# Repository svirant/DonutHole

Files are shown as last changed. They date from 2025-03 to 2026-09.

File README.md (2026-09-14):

# Donut Hole

**mini version of the [Donut Dongle](https://github.com/svirant/DonutDongle) that enables auto profiles for RS-232 based switches for the RetroTink 4K Pro/CE**
 - 3DP case now available on [MakerWorld](https://makerworld.com/en/models/1433467-donut-hole-for-retrotink-4k?from=search#profileId-1490991)
 - Compatible with the SVS
 - Connect multiple Donut Holes, Donut Dongles, gSerial Enablers simultaneously via a headphone jack splitter.
   - Must reflash "firmware" with offset variable set so SVS profile numbers don't overlap.
   - Up to 5 have been connected together simultaneously. More may be supported, but this is the max number I've been able to test.
 - Full instructions listed below for building your own!

> [!TIP]
> If DIY is not your thing. I have assembled versions available in my [Ko-fi](https://ko-fi.com/donutswdad/shop) shop.
</br>

> [!NOTE]
> *NEW* version allows:
> <br /> 
>   - **MT-VIKI Disconnection Detection** - when an input is powered off and on, the profile is resent.
>     - **Disable MT-VIKI beeping by pressing the "#" button on its remote.**
>   - **front case buttons/remote NOW change profiles on the MT-VIKI HDMI switch.** Thanks to [Arthrimus](https://scalablevideoswitch.com/)! 
>   - **auto-switching on Extron Matrix switchers** that support DSVP. Works with RGBS/HV and HDMI/DVI signal types.
>   - **Support for older Extron Crosspoint (non plus) matrix switchers**
>
> 
> <br /> For Matrix auto-switching, use the follow Options to enable:
> ```
> #define automatrixSW1 true // set true for auto matrix switching on "SW1" port
> #define automatrixSW2 false // set true for auto matrix switching on "SW2" port
>
> uint8_t ExtronVideoOutputPortSW1 = 1; // For older (E-series,non Plus/Ultra) Extron Matrix models, must specify the video output port that connects to RT4K
> uint8_t ExtronVideoOutputPortSW2 = 1; 
>
> uint8_t const vinMatrix[] = {0,  // MATRIX switchers  // When auto matrix mode is enabled: (automatrixSW1 / SW2 defined above)
>                                                        // set to 0 for the auto switched input to tie to all outputs
>                                                        // set to 1 for the auto switched input to trigger a Preset
>                                                        // set to 2 for the auto switched input to tie to "ExtronVideoOutputPortSW1" / "ExtronVideoOutputPortSW2"
>                                                        //
>                                                        // For option 1, set the following inputs to the desired Preset #
>                                                        // (by default each input # is set to the same corresponding Preset #)
> ```
<br />
<br />

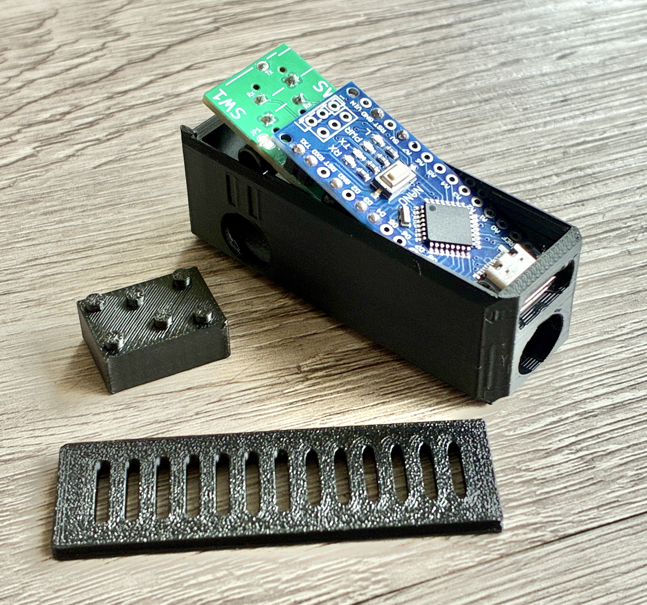
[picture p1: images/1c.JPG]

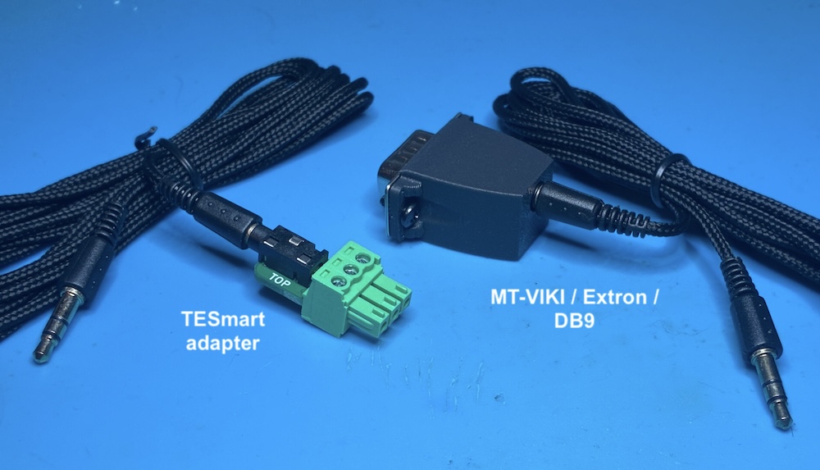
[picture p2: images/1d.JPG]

<br />

# Supported Switches
(current list, but not limited to)
| **Switch** | Supported | Notes |
| --- | --- |--- |
| TESmart 16x1 HDMI  | yes, confirmed first hand  | [Amazon](https://a.co/d/9XwZDlt) link for reference|
| TESmart 8x1 HDMI  | unconfirmed, but should work, let me know! | |
| MT-VIKI 8 port HDMI | yes, confirmed first hand | [Amazon](https://a.co/d/eHo5uKs) link for reference. **Disable MT-VIKI beeping by pressing the "#" button on it's remote.** |
| Extron RGBHV sw6  | yes, confirmed first hand  | auto-profiles triggered by manual selection or auto-switching |
| Extron SW4 VGA Ars | yes, confirmed by "Nobody" on the RT4K Discord | auto-profiles triggered by manual selection or auto-switching |
| Extron DXP 88 | yes, confirmed first hand | Auto-switching can be enabled in "Options" section of .ino.  Works with Presets. On SW1, Preset 1 is S1_ profile. On SW2, Preset 1 is S101_ profile, etc. <br><br>Power up the switch before connecting the DonutHole. |
| Extron CrossPoint Plus, MVX, etc | yes, confirmed by other users | Auto-switching can be enabled for switches that supports DSVP and are RGBS/HDMI/DVI signal types. By default, works with Presets as shown in the Note above. |
| Extron CrossPoint E-series  | yes, works with Presets and Input changes | Must set ExtronVideoOutputPortSW1 / SW2 variable to output connected to RT4K |

<br />

# Ordering PCBs
PCBs for this project:
 - [Donut Hole](https://github.com/svirant/DonutHole/blob/main/Donut_Hole.zip)
 - [VGA Adapter](https://github.com/svirant/DonutDongle/tree/main/Adapters) (VGAPassthrough or YC2VGA)
- (Optional) [TESmart_connector](https://github.com/svirant/DonutDongle/tree/main/Accessories)
- (Optional) [MT-VIKI / Extron / DB9 adapter](https://github.com/svirant/DonutDongle/tree/main/Accessories)
 
There are plenty of options for PCB manufacturing but I prefer [JLCPCB](https://jlcpcb.com) (No affiliation). Using the gerber (.zip) files provided, it's easy to place an order. Below are some tips/guidelines:
- 1.6mm Thickness
- For Surface Finish, "HASL(with lead)" is fine
- 4 Layer PCBs are the same cost as 2 Layer for the VGA Adapters. Because of that, the inner 2 layers are being used as ground planes for better EMI protection. Thanks to https://x.com/zaxour for the idea!
- "Remove Mark" option is now free on JLCPCB. Use it!
- All remaining default options should be fine
- Let me know if you have any questions!

# Assembly

[Interactive HTML BOM](https://svirant.github.io/DonutHole/images/ibom.html)

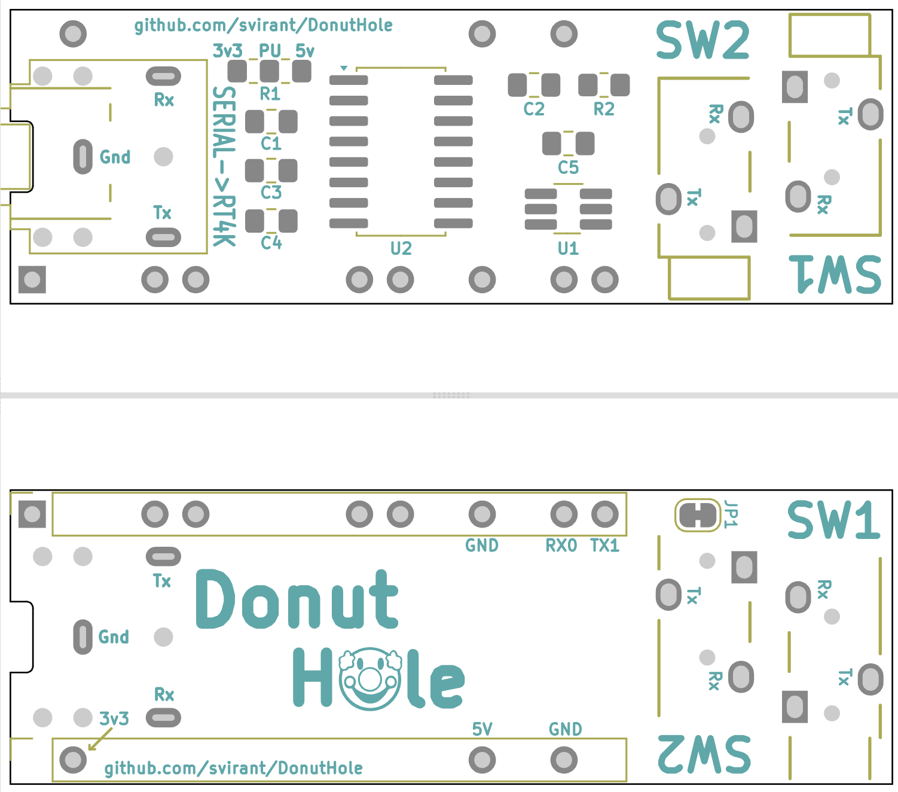
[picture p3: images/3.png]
[](https://svirant.github.io/DonutHole/images/ibom.html)

# (2M) baud mod
- **NOT supported with SVS connected to VGA adapter**
  - ...unless SDA/SDL trace is cut on VGA Adapter, but that disables the SVS's profile sending.
  - SVS runs at 9600 baud which conflicts with 2M regardless.
  - Extra Tx/Rx wire length of VGA cable can also cause issues. Workaround - You can cut SDA/SDL traces on the bottom of the VGA adapter to continue passing video but disables "VGA cable Serial" passthrough. (How the SVS sends profile changes)

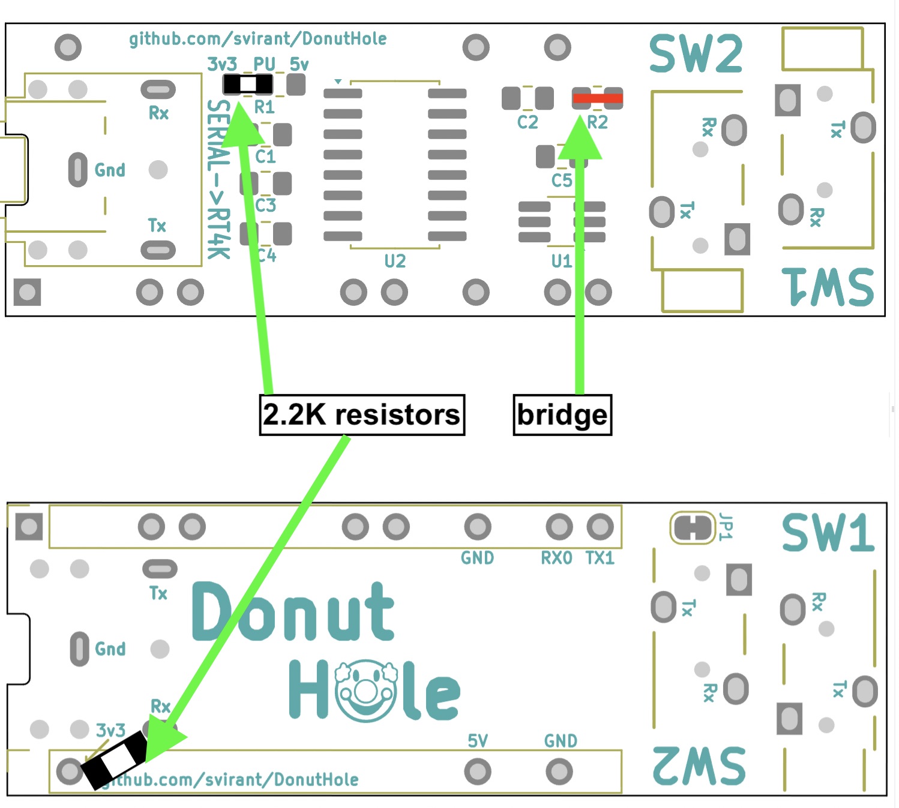
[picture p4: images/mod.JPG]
<p>
 - Replace R1 (10K) with a 2.2K resistor
 - Remove R2 and bridge pads
 - Connect Rx and 3.3v with a 2.2K resistor 
 <br><br>

# PCB
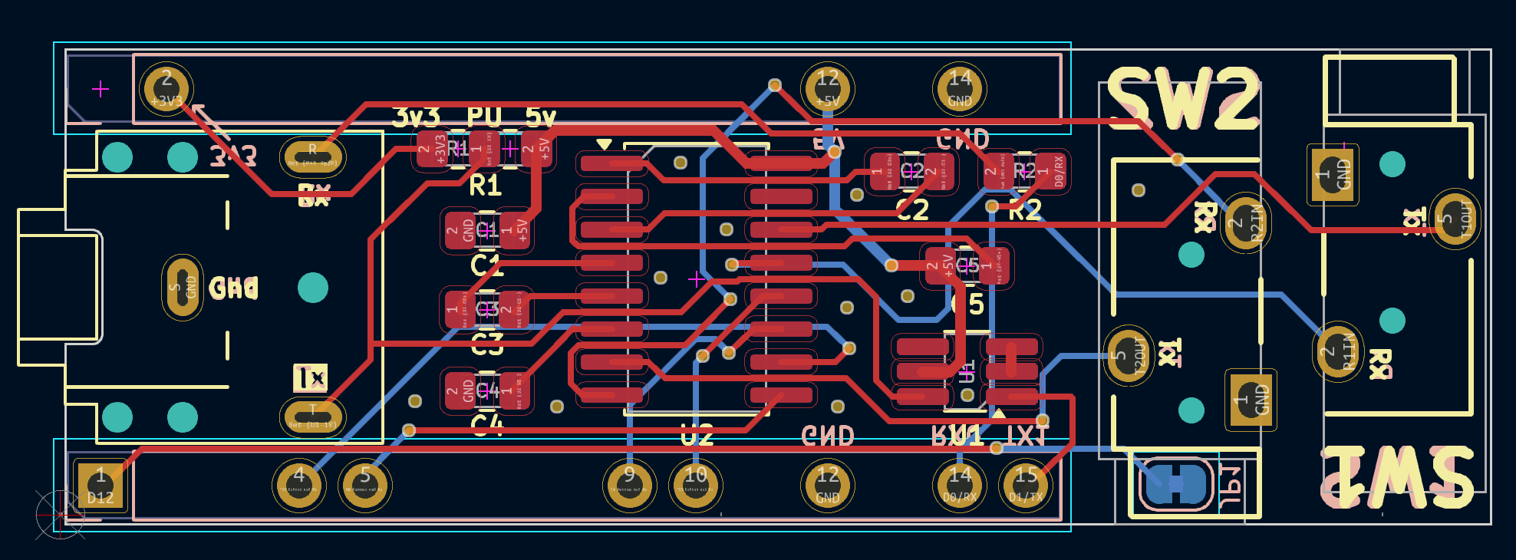
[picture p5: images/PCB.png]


# Schematic
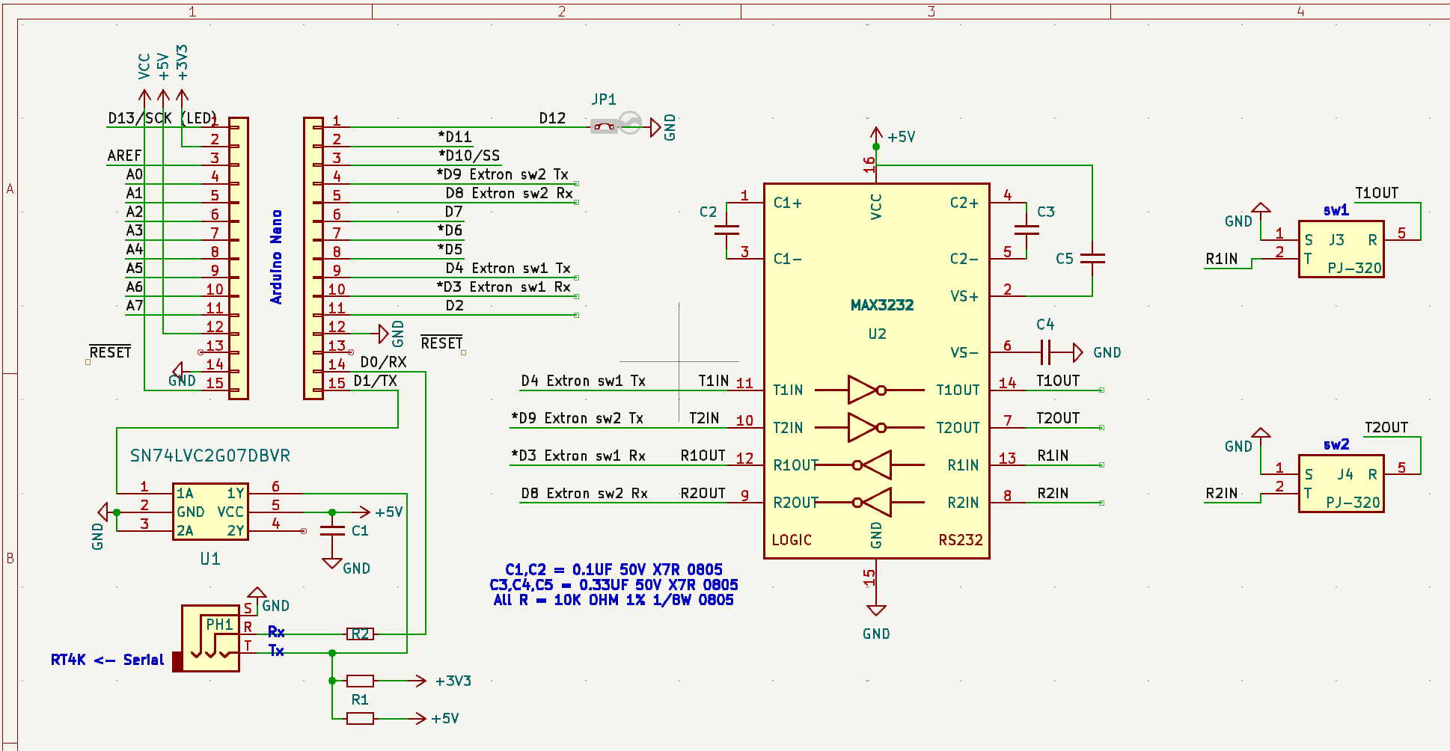
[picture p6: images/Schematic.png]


## Bill of Materials (BOM)

| **Qty** | Designation | Part |  Link  |  Notes |
| --- | --- |--- |--- |--- |
| 2  | C1,C2 | 0.1 uf / 100nf 50V X7R 0805 Capacitor| [Digikey](https://www.digikey.com/en/products/detail/yageo/CC0805KRX7R9BB104/302874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) | |
| 3  | C3 - C5 | 0.3 uf / 330nf 50V X7R 0805 Capacitor| [Digikey](https://www.digikey.com/en/products/detail/samsung-electro-mechanics/CL21B334KBFNNNE/3886781) | |
| 2  | R1, R2 | 10K OHM 1% 1/8W 0805 Resistor | [Digikey](https://www.digikey.com/en/products/detail/yageo/AC0805FR-0710KL/2827834) | |
| 1  | U1 | IC BUF NON-INVERT 5.5V SOT23-6 | [Digikey](https://www.digikey.com/en/products/detail/texas-instruments/SN74LVC2G07DBVR/486427) or [alternate](https://www.digikey.com/en/products/detail/umw/SN74LVC2G07DBVR/24889644) | |
| 1  | U2 | MAX3232 SOP-16 RS-232 Interface IC | [AliExpress](https://www.aliexpress.us/item/3256807314260762.html) | |
| 1  | PH1 | PJ-307 3.5mm Stereo Jack | [AliExpress](https://www.aliexpress.us/item/3256805624175150.html) | |
| | |  or **1x** 3.5mm Audio Jack Socket | [AliExpress](https://www.aliexpress.us/item/2251832685563184.html) | Like the PJ-307 but missing the inner 2 poles which arent needed anyways |
| 2  | J2 | PJ-320 3.5MM Headphone Jack Audio Video Female | [AliExpress](https://www.aliexpress.us/item/3256807448104402.html) | Color: PJ-320B DIP | 
| 11  | J3,J4 | 2.54mm male pin headers | break off the male headers that come with the Arduino Nano | | 
| 1  | | Arduino Nano type c | Support [RetroRGB!](https://amzn.to/4gnHqN4) | Make sure the headers are not soldered. |
| 1  | | Any 3.5mm / aux / stereo / trs / cable | [AliExpress](https://www.aliexpress.us/item/2255799962255486.html) | |
| 1  | | usb-c cable for Arduino power & programming | [AliExpress](https://www.aliexpress.us/item/3256806983355947.html) | |
| (needed for RS-232 DB9 connections) | | MT-VIKI / Extron / DB9 adapter | [DIY](https://github.com/svirant/DonutDongle/tree/main/Accessories) | ...or purchase from below |
| | | DB9 Male to 3.5mm Male Serial RS232 Cable 6feet | [Amazon](https://www.amazon.com/LIANSHU-DC3-5mm-Serial-RS232-Cable/dp/B07G2ZL3SL/) | "MUST" be wired as so: [DB9 Male Pin 5 -> Sleeve, DB9 Male Pin 2 -> Tip, DB9 Male Pin 3 -> Ring](/images/7.png) |

# Programming an Arduino Nano
I recommend the [Official Arduino IDE and guide](https://www.arduino.cc/en/Guide) if you're unfamiliar with Arduinos. All .ino files used for programming are listed above. The following Library will also need to be added in order to Compile successfully.<br />
- **Libraries:**
  - <AltSoftSerial.h>  Follow these steps to add AltSoftSerial.h
    - Goto https://github.com/PaulStoffregen/AltSoftSerial
    - Click the GREEN "<> Code" box and "Download ZIP"
    - In Arudino IDE; goto "Sketch" -> "Include Library" -> "Add .ZIP Library"

Some Arduino Nanos come with an Old Bootloader and won't Upload unless specified. **If you get errors** when trying to upload, swap to this option as a possible fix.

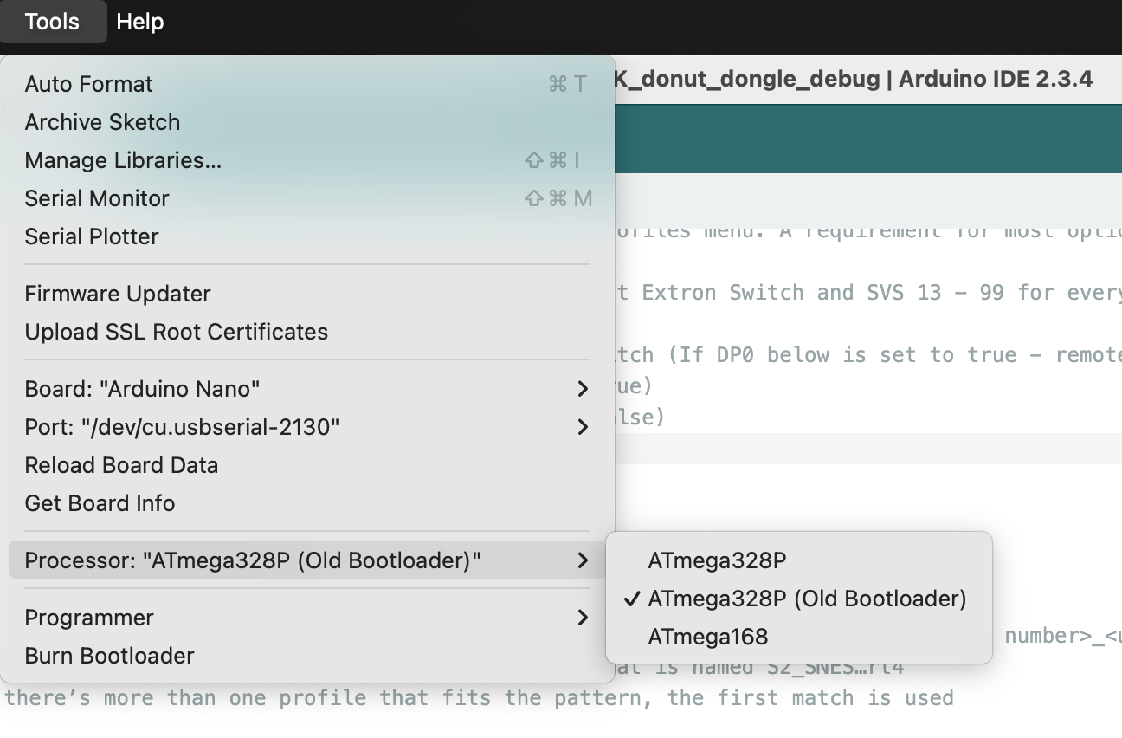
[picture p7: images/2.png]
bootloader


## Steps to update offset
 - 1 - Download and install the [Arduino IDE](https://www.arduino.cc/en/software/) for your PC or Mac
 - 2 - Click the green "<> Code" button above and "Download ZIP".
 - 3 - Extract the .zip file and open up the "Donut_Hole.ino" file in the Arduino IDE. It will ask if you would like to move this file inside a folder, select OK.
 - 4 - With the source code now open, select "Tools" -> "Board" -> "Arduino AVR Boards" -> "Arduino Nano"
 - 5 - Connect the Donut Hole device to your PC or Mac using the usb-c cable. You should see an LED light up when connected.
 - 6 - With the Donut Hole now connected, select it's "port" by going to "Tools" -> "Port", and select the port that starts with "/dev/cu.usbserial-" (on Mac) or "COM" if on PC.
 - 7 - Almost done! :) In the code itself, find the line that starts with "uint16_t const offset = 0;" and change the 0 to 300. It should now look like this: uint16_t const offset = 300;
   - This will give you profiles 301 - 399 for SW1 and 401 - 499 for SW2
   - At the moment this is line 32
 - 8 - From the menu at the top, select "Sketch" -> "Upload". You should see the LEDs on the Donut Hole flicker and a message that says "Done uploading." if successful.
   - If you get errors, see the section above about changing the "Bootloader" type.
 - 9 - Disconnect the usb-c cable from your computer and give it a whirl! You can repeat these steps in the future to make any other changes or update if a newer firmware is ever released.

  -----------
# How to Use
- Make sure **"Auto Load SVS"** is **"On"** under the RT4K Profiles menu.  
- The RT4K checks the **/profile/SVS** subfolder for profiles and need to be named: **S\<input number>_\<user defined>.rt4**  For example, SVS input 1 would look for a profile that is named S1_SNES.rt4.  If there’s more than one profile that fits the pattern, the first match is used.

- Check the RT4K Diagnostic Console for Serial commands being received as confirmation.

## SVS Profile numbering scheme

**Input 1-10... = S1_ - S10_ ...,etc**

The "offset" option can be used if using multiple Donut Holes, gSerial Enablers, Donut Dongles are connected to the RT4K via a headphone splitter. For example, if using a 2nd, change "offset = 300" for the 2nd device to be SVS profiles 301 - 310.

```
uint16_t const offset = 0; // Only needed for multiple Donut Holes, gSerial Enablers, Donut Dongles. Set offset so 2nd, 3rd, etc gSEs don't overlap profiles. (e.g. offset = 300;) 
```

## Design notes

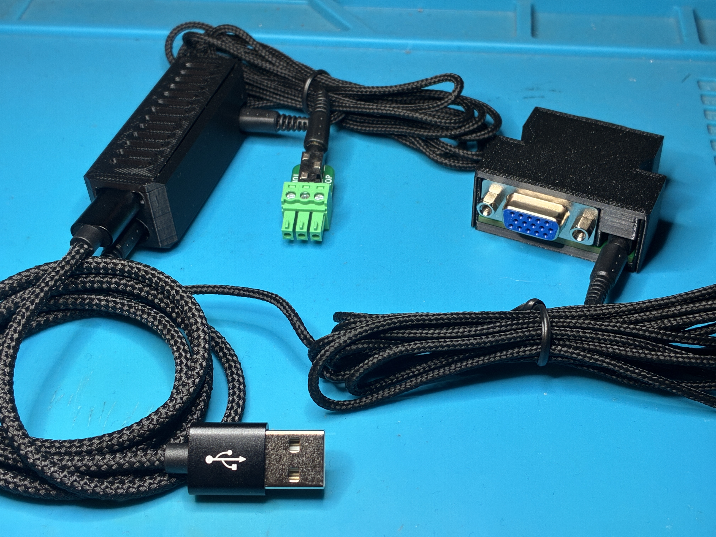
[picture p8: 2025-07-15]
images/1b.JPG

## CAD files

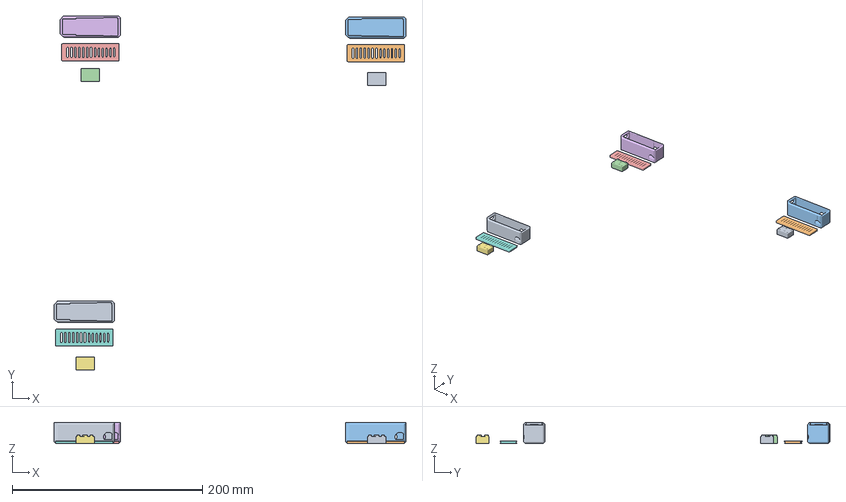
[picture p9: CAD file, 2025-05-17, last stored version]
Donut_Hole.3mf
369.5 x 371.8 x 22.1 mm
Lego Block x 3
Slide Top x 3
Donut Hole x 3

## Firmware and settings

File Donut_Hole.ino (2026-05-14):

/*
* Donut Hole v0.6m
* Copyright (C) 2026 @Donutswdad
*
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
* You should have received a copy of the GNU General Public License
* along with this program.  If not, see <http://www.gnu.org/licenses/>.
*/

#include <SoftwareSerial.h>
#include <AltSoftSerial.h>  // https://github.com/PaulStoffregen/AltSoftSerial in order to have a 3rd Serial port for SW2
                            // Step 1 - Goto the github link above. Click the GREEN "<> Code" box and "Download ZIP"
                            // Step 2 - In Arudino IDE; goto "Sketch" -> "Include Library" -> "Add .ZIP Library"

#define EXTRON1 0
#define EXTRON2 1
#define MAX_BYTES 50
#define MAX_EINPUT 36
#define MTV_TIME_CHECK 1500 // time between mt-viki disconnetion detection checks
#define AM_TIME_CHECK 500 // time between auto-matrix input change detection

struct profileorder {
  int Prof;
  uint8_t On;
  uint8_t King;
};

profileorder mswitch[2] = {{0,0,0},{0,0,0}};
uint8_t mswitchSize = 2;

/*
////////////////////
//    OPTIONS    //
//////////////////
*/

uint8_t const debugE1CAP = 0; // line ~276
uint8_t const debugE2CAP = 0; // line ~535

uint16_t const offset = 0; // Only needed if multiple Donut Holes, gSerial Enablers, Donut Dongles are connected. Set offset so 2nd, 3rd, etc don't overlap profiles. (e.g. offset = 100;) 

bool S0 = false;   // (Profile 0) default is false
                         //  ** Recommended to leave this option "false" if using in tandem with other Serial devices. **
                         // If set to "true", "S0_<user definted>.rt4" will load when all inputs are in-active on SW1 (and SW2 if connected). 
                         // ** Does not work with MT-VIKI / TESmart HDMI switches **

// For Extron Matrix switches that support DSVP. RGBS and HDMI/DVI video types.
#define automatrixSW1 false // set true for auto matrix switching on "SW1" port
#define automatrixSW2 false // set true for auto matrix switching on "SW2" port

uint8_t ExtronVideoOutputPortSW1 = 1; // For older (E-series,non Plus/Ultra) Extron Matrix models, must specify the video output port that connects to RT4K
uint8_t ExtronVideoOutputPortSW2 = 1; 

uint8_t const vinMatrix[] = {0,  // MATRIX switchers  // When auto matrix mode is enabled: (automatrixSW1 / SW2 defined above)
                                                        // set to 0 for the auto switched input to tie to all outputs
                                                        // set to 1 for the auto switched input to trigger a Preset
                                                        // set to 2 for the auto switched input to tie to "ExtronVideoOutputPortSW1" / "ExtronVideoOutputPortSW2"
                                                        //
                                                        // For option 1, set the following inputs to the desired Preset #
                                                        // (by default each input # is set to the same corresponding Preset #)
                           1,  // input 1 SW1
                           2,  // input 2
                           3,  // input 3
                           4,  // input 4
                           5,  // input 5
                           6,  // input 6
                           7,  // input 7
                           8,  // input 8
                           9,  // input 9
                           10,  // input 10
                           11,  // input 11
                           12,  // input 12
                           13,  // input 13
                           14,  // input 14
                           15,  // input 15
                           16,  // input 16
                           17,  // input 17
                           18,  // input 18
                           19,  // input 19
                           20,  // input 20
                           21,  // input 21
                           22,  // input 22
                           23,  // input 23
                           24,  // input 24
                           25,  // input 25
                           26,  // input 26
                           27,  // input 27
                           28,  // input 28
                           29,  // input 29
                           30,  // input 30
                           30,  // input 31
                           30,  // input 32
                               //
                               // ONLY USE FOR 2ND MATRIX SWITCH on SW2
                           1,  // 2ND MATRIX SWITCH input 1 SW2
                           2,  // 2ND MATRIX SWITCH input 2
                           3,  // 2ND MATRIX SWITCH input 3
                           4,  // 2ND MATRIX SWITCH input 4
                           5,  // 2ND MATRIX SWITCH input 5
                           6,  // 2ND MATRIX SWITCH input 6
                           7,  // 2ND MATRIX SWITCH input 7
                           8,  // 2ND MATRIX SWITCH input 8
                           9,  // 2ND MATRIX SWITCH input 9
                           10,  // 2ND MATRIX SWITCH input 10
                           11,  // 2ND MATRIX SWITCH input 11
                           12,  // 2ND MATRIX SWITCH input 12
                           13,  // 2ND MATRIX SWITCH input 13
                           14,  // 2ND MATRIX SWITCH input 14
                           15,  // 2ND MATRIX SWITCH input 15
                           16,  // 2ND MATRIX SWITCH input 16
                           17,  // 2ND MATRIX SWITCH input 17
                           18,  // 2ND MATRIX SWITCH input 18
                           19,  // 2ND MATRIX SWITCH input 19
                           20,  // 2ND MATRIX SWITCH input 20
                           21,  // 2ND MATRIX SWITCH input 21
                           22,  // 2ND MATRIX SWITCH input 22
                           23,  // 2ND MATRIX SWITCH input 23
                           24,  // 2ND MATRIX SWITCH input 24
                           25,  // 2ND MATRIX SWITCH input 25
                           26,  // 2ND MATRIX SWITCH input 26
                           27,  // 2ND MATRIX SWITCH input 27
                           28,  // 2ND MATRIX SWITCH input 28
                           29,  // 2ND MATRIX SWITCH input 29
                           30,  // 2ND MATRIX SWITCH input 30
                           30,  // 2ND MATRIX SWITCH input 31
                           30,  // 2ND MATRIX SWITCH input 32
                           };

                           
////////////////////////////////////////////////////////////////////////

// automatrix variables
#if automatrixSW1 || automatrixSW2
uint8_t AMstate[32];
uint32_t prevAMstate = 0;
int  AMstateTop = -1;
uint8_t amSizeSW1 = 8; // 8 by default, but updates if a different size is discovered
uint8_t amSizeSW2 = 8; // ...
#endif

// SW1 software serial port -> MAX3232 TTL IC
SoftwareSerial extronSerial = SoftwareSerial(3,4); // setup a software serial port for listening to SW1. rxPin = 3 / txPin = 4

// SW2 software serial port -> MAX3232 TTL IC
AltSoftSerial extronSerial2; // setup yet another serial port for listening to SW2. hardcoded to pins D8 / D9

// Extron Global variables
uint8_t eoutput[2]; // used to store Extron output
int currentInputSW1 = -1;
int currentInputSW2 = -1;
int currentProf = 0;
char ecap[MAX_BYTES] = {};
char einput[MAX_EINPUT] = {};
byte ecapbytes[MAX_BYTES] = {0}; // used to store first MAX_BYTES bytes / messages for Extron capture
byte const VERB[5] = {0x57,0x33,0x43,0x56,0x7C}; // sets matrix switch to verbose level 3
bool ReconfigSet[2] = {false,false};

// MT-VIKI serial command
byte viki[4] = {0xA5,0x5A,0x00,0xCC};

// LS Time variables
unsigned long LScurrentTime = 0; 
unsigned long LScurrentTime2 = 0;
unsigned long LSprevTime = 0;
unsigned long LSprevTime2 = 0;

#if !automatrixSW1
// MT-VIKI Time variables
unsigned long MTVcurrentTime = 0; 
unsigned long MTVprevTime = 0;
unsigned long sendtimer = 0;
unsigned long ITEtimer = 0;
#endif

#if !automatrixSW2
// MT-VIKI Time variables
unsigned long MTVcurrentTime2 = 0;
unsigned long MTVprevTime2 = 0;
unsigned long sendtimer2 = 0;
unsigned long ITEtimer2 = 0;
#endif

// MT-VIKI Manual Switch variables
uint8_t ITEstatus[] = {3,2,0};
uint8_t ITEstatus2[] = {3,2,0};
bool ITErecv[2] = {0,0};
bool listenITE[2] = {1,1};
uint8_t ITEinputnum[2] = {0,0};
uint8_t currentMTVinput[2] = {0,0};
bool MTVdiscon[2] = {false,false};
bool MTVddSW1 = false;
bool MTVddSW2 = false;

////////////////////////////////////////////////////////////////////////

void setup(){

  Serial.begin(9600); // set the baud rate for the RT4K Serial Connection
  while(!Serial){;}   // allow connection to establish before continuing
  extronSerial.begin(9600); // set the baud rate for the Extron sw1 Connection
  extronSerial.setTimeout(50); // sets the timeout for reading / saving into a string
  extronSerial2.begin(9600); // set the baud rate for Extron sw2 Connection
  extronSerial2.setTimeout(50); // sets the timeout for reading / saving into a string for the Extron sw2 Connection
  memset(ecap,0,sizeof(ecap)); // set to all 0s
  memset(einput,0,sizeof(einput)); // set to all 0s
  pinMode(12,INPUT_PULLUP);
  delay(100);
  if(digitalRead(12) == HIGH) S0 = true; // check state of JP1 jumper. closed jumper disables S0, cut trace / open jumper enables S0.

}

void loop(){

  readExtron1(); // also reads TESmart, MT-VIKI HDMI switches
  readExtron2(); // also reads TESmart, MT-VIKI HDMI switches
} // end of loop()

bool substringEquals(const char* buffer, int start, int end, const char* compareTo){
  size_t len = end - start;
  for(size_t i=0;i < len;i++){
    if(tolower(buffer[start + i]) != tolower(compareTo[i])) return false;
  }
  return true;
} // end of substringEquals()

void copySnippet(const char* src, int start, int end, char* dest){
  size_t len = end - start;
  for(size_t i=0;i < len;i++){
    dest[i] = src[start + i];
  }
} // end of copySnippet()

int sliceToInt(const char* buffer, int start, int end){
  int value = 0;
  for(int i = start; i < end; i++){
    if(buffer[i] < '0' || buffer[i] > '9') break;
    value = value * 10 + (buffer[i] - '0');
  }
  return value;
} // end of sliceToInt()

uint8_t lengthUpToLineEnding(const char* buffer, uint8_t bufLen){
  for(uint8_t i = 0; i < bufLen; i++){
    if(buffer[i] == '\r' || buffer[i] == '\n'){
      return i;  // stop at first line ending
    }
  }
  return bufLen;  // no line ending found, full length
} // end of lengthUpToLineEnding()

void readExtron1(){

  #if automatrixSW1 // if automatrixSW1 is set "true" in options, then "0LS" is sent every 500ms to see if an input has changed
      LS0time1(AM_TIME_CHECK);
  #endif

  #if !automatrixSW1
    if(MTVddSW1){            // if a MT-VIKI switch has been detected on SW1, then the currently active MT-VIKI hdmi port is checked for disconnection
      MTVtime1(MTV_TIME_CHECK);
    }
  #endif

    // listens to the Extron sw1 Port for changes
    // SIS Command Responses reference - Page 77 https://media.extron.com/public/download/files/userman/XP300_Matrix_B.pdf
    if(extronSerial.available() > 0){ // if there is data available for reading, read
      extronSerial.readBytes(ecapbytes,MAX_BYTES); // read in and store only the first MAX_BYTES bytes for every status message received from 1st Extron SW port
      if(debugE1CAP){
        Serial.print(F("ecap HEX: "));
        for(int i=0;i<MAX_BYTES;i++){
          Serial.print(ecapbytes[i],HEX);Serial.print(F(" "));
        }
        Serial.println(F("\r"));
        memcpy(ecap,ecapbytes,MAX_BYTES);
        Serial.print(F("ecap ASCII: "));Serial.println(ecap);
      }
    }
    if(!debugE1CAP) memcpy(ecap,ecapbytes,MAX_BYTES);


    if(substringEquals(ecap,0,3,"OUT") && !automatrixSW1){ // store only the input and output states, some Extron devices report output first instead of input
      if(substringEquals(ecap,4,5," ")){
        copySnippet(ecap,5,9,einput);
        if(sliceToInt(ecap,3,4) == ExtronVideoOutputPortSW1) eoutput[0] = 1;
        else eoutput[0] = 0;
      }
      else{
        copySnippet(ecap,6,10,einput);
        if(sliceToInt(ecap,3,5) == ExtronVideoOutputPortSW1) eoutput[0] = 1;
        else eoutput[0] = 0;
      }
    }
    else if(substringEquals(ecap,0,1,"F")){ // detect if switch has changed auto/manual states
      copySnippet(ecap,4,8,einput);
      eoutput[0] = 1;
    }
    else if(substringEquals(ecap,0,3,"Rpr")){ // detect if a Preset has been used
      copySnippet(ecap,0,5,einput);
      eoutput[0] = 1;
    }
    else if(substringEquals(ecap,0,8,"RECONFIG")){      // This is received everytime a change is made on older Extron Crosspoints
      ReconfigSet[0] = true;
      char cmd[10];
      snprintf(cmd, sizeof(cmd), "v%d%%", ExtronVideoOutputPortSW1);
      extronSerial.write(cmd);
      delay(20);
    }
#if automatrixSW1
    else if(substringEquals(ecap,amSizeSW1 + 6,amSizeSW1 + 9,"Rpr")){ // detect if a Preset has been used 
      copySnippet(ecap,amSizeSW1 + 6,amSizeSW1 + 11,einput);
      eoutput[0] = 1;
    }
    else if(substringEquals(ecap,amSizeSW1 + 7,amSizeSW1 + 10,"Rpr")){ // detect if a Preset has been used 
      copySnippet(ecap,amSizeSW1 + 7,amSizeSW1 + 12,einput);
      eoutput[0] = 1;
    }
    else if(substringEquals(ecap,0,3,"In0") && !substringEquals(ecap,4,7,"All") && !substringEquals(ecap,5,8,"All")){ // start of automatrix
      if(substringEquals(ecap,0,4,"In00")){
        amSizeSW1 = lengthUpToLineEnding(ecap,MAX_BYTES) - 5;
        copySnippet(ecap,5,amSizeSW1 + 5,einput);
      }
      else{
        amSizeSW1 = lengthUpToLineEnding(ecap,MAX_BYTES) - 4;
        copySnippet(ecap,4,amSizeSW1 + 4,einput);
      }
      uint8_t check = readAMstate(einput,amSizeSW1);
      if(check != currentInputSW1){
        currentInputSW1 = check;
        if(currentInputSW1 == 0){
          setTie(currentInputSW1,1);
          sendProfile(0,EXTRON1,1);
        }
        else if(vinMatrix[0] == 1){
          recallPreset(vinMatrix[currentInputSW1],1);
        }
        else if(vinMatrix[0] == 0 || vinMatrix[0] == 2){
          setTie(currentInputSW1,1);          
          sendProfile(currentInputSW1,EXTRON1,1);
        }
      }
    }
    else if(substringEquals(ecap,0,10,"00000000\r\n") || substringEquals(ecap,0,14,"000000000000\r\n")
            || substringEquals(ecap,0,18,"0000000000000000\r\n")
            || substringEquals(ecap,0,26,"000000000000000000000000\r\n")
            || substringEquals(ecap,0,34,"00000000000000000000000000000000\r\n")){
      extronSerial.write(VERB,5); // sets extron matrix switch to Verbose level 3
    } // end of Verbose check
#endif
    else{                             // less complex switches only report input status, no output status
      copySnippet(ecap,0,4,einput);
      eoutput[0] = 1;
    }

    // For older Extron Crosspoints, where "RECONFIG" is sent when changes are made, the profile is only changed when a different input is selected for the defined output. (ExtronVideoOutputPortSW1)
    // Without this, the profile would be resent when changes to other outputs are selected.
    if(substringEquals(einput,0,2,"IN") && sliceToInt(einput,2,4) == currentProf && ReconfigSet[0]){
      ReconfigSet[0] = false;
      copySnippet("XX00",0,4,einput);
    }

    // for Extron devices, use remaining results to see which input is now active and change profile accordingly, cross-references eoutput[0]
    if((substringEquals(einput,0,2,"IN") && eoutput[0] && !automatrixSW1) || substringEquals(einput,0,3,"Rpr")){
      if(substringEquals(einput,0,3,"Rpr")){
        sendProfile(sliceToInt(einput,3,5),EXTRON1,1);
      }
      else if(!substringEquals(einput,0,4,"IN0 ") && !substringEquals(einput,0,4,"In0 ") && !substringEquals(einput,0,4,"In00")){ // for inputs 1-99 (SVS only)
        sendProfile(sliceToInt(einput,2,4),EXTRON1,1);
      }
      else if(substringEquals(einput,0,4,"IN0 ") || substringEquals(einput,0,4,"In0 ") || substringEquals(einput,0,4,"In00")){
        sendProfile(0,EXTRON1,1);
      }
    }
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

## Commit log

2025-03-17 update BOM
2025-03-20 added "return" character before every serial command to clear out buffer. needed when sharing TX bus with other devices.
2025-03-26 updated BOM w/ alternate IC for U1
2025-04-29 step file for 3D case
2025-05-04 added 3D printed case
    [Donut_Hole.3mf]
2025-05-04 updated 3D print design
    [Donut_Hole.3mf]
2025-05-04 yet another 3D case update
    [Donut_Hole.3mf]
2025-05-06 added SNES multi-color variant
    [Donut_Hole.3mf]
2025-05-14 added snug supports for holes, consistent outer wall speed for even finish
    [Donut_Hole.3mf]
2025-05-14 tweaked snug supports
    [Donut_Hole.3mf]
2025-05-17 removed snug supports
    [Donut_Hole.3mf]
2025-05-20 moved 3DP case link to MakerWorld
    [Donut_Hole.3mf]
2025-07-09 added MT-VIKI / Extron / DB9 PCB info
2025-07-13 changed delays to timers and now Presets work again when in automatrix mode
2025-07-13 possible fix for some crosspoints switching to an input / sending a profile that is +1 higher
2025-07-13 added support for up to 32x32 matrix switches
2025-07-14 fixed bug where SW2 in automatrix mode sent same profile #s as SW1. S0_ profile now works with mixed automatrix and regular Extron switches
2025-07-15 updated bom and pictures
2025-07-15 fixed Presets sometimes not being detected. auto switching can now be set to output to ALL outputs
2025-07-15 previous Presets bug should now also be fixed for matrix switches that report In00 vs In0
2025-08-12 S0 profile is no longer affected by offset
    [Donut_Hole.ino]
2025-08-14 HUGE! Thanks to Arthrimus, MT-VIKI face buttons now send profiles.
2025-08-19 updated supported switch notes, pictures
2025-10-23 updated BOM to potentially help with "hot plugging" 3.5mm rs-232 connections. not recommended, can lockup max3232 IC
2025-12-09 adds hdmi input disconnection detection (takes a few seconds), resends profile when powered back on.
    this allows the profile to be resent when the console if powered off and on the same hdmi input port. auto-switching seems solid, but the manual button presses to change inputs need to be "primed" by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
2025-12-09 fixed bug where front case and IR remote buttons may not respond properly
2025-12-09 fixed yet another bug where front case and IR remote buttons may not respond properly. last one? should be!
2025-12-10 fixed timing condition that could cause some auto-switches not to send a profile
    if disconnection detection and auto-switch occur during the same cycle, the auto-switch command could be missed thus no profile sent.
2025-12-10 typos and edge case fix for case buttons
2026-01-18 fixed command sent when "RECONFIG" is received from Extron switchers
2026-01-19 fixed bug where older Extron Crosspoints wouldnt be able to switch from input 1 to 11. moved "RECONFIG" response into its own function.
2026-02-04 when all consoles are off on SW1, will change profiles back to SW2 if there are active consoles and vice versa. Switches most report when they have no active connections for this feature to work.
2026-02-18 automatically sets automatrix switch to Verbose 3 if the switch reboots.
2026-02-18 Added support for 12 port Extron Matrix switches to automatically enable Verbose 3 mode when in automatrix mode.
2026-03-02 fixed long standing bug that would have caused changing inputs on the MT-VIKI via panel buttons to not work in certain scenarios
2026-03-13 fixed regression bug for Extron switches that respond with single digit input. Ex: "In1 " vs "In01"
    [Donut_Hole.ino]

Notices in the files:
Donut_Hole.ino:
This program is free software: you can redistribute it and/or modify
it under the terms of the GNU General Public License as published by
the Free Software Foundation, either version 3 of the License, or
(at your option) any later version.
